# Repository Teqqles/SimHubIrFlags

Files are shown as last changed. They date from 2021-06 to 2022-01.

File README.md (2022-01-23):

# SimHubIrFlags

Custom serial device for pushing SimHub flag colours to inexpensive IR controlled RGB light strips.  Your mileage may vary on this project depending on which
IR light strips you are using.  Some for example have more latency than others, they do not allow for coloured light flashing, etc.

## Circuit 

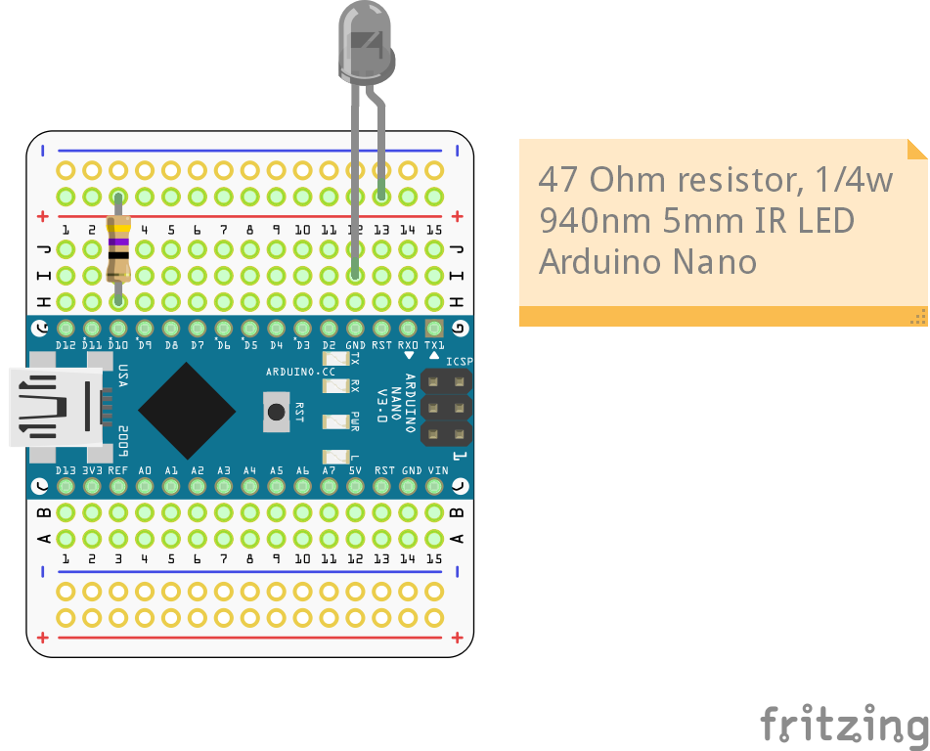
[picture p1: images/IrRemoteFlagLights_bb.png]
IR Circuit


## Parts

The parts I used in this project were:

- Cytron Maker Nano - https://thepihut.com/products/maker-nano <br>
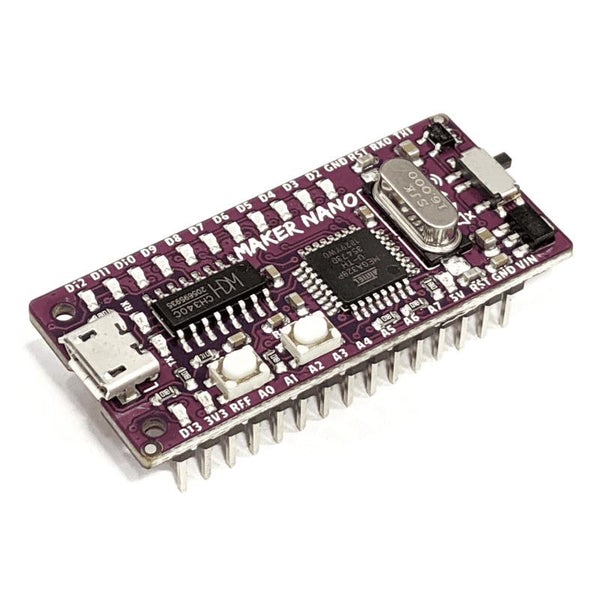
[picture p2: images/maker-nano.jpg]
Maker Nano
  
- 47 Ohm 1/4w Resistor - https://www.amazon.co.uk/Watt-Carbon-Resistor-0-25W-Tolerance/dp/B08Y2S1S6Z <br>
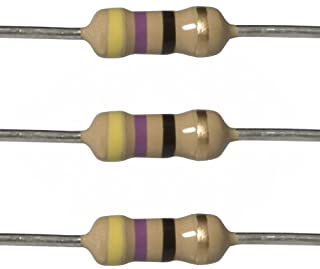
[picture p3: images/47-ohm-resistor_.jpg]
Resistor
  
- 940nm IR LED 5mm Package - https://thepihut.com/products/super-bright-5mm-ir-led <br>
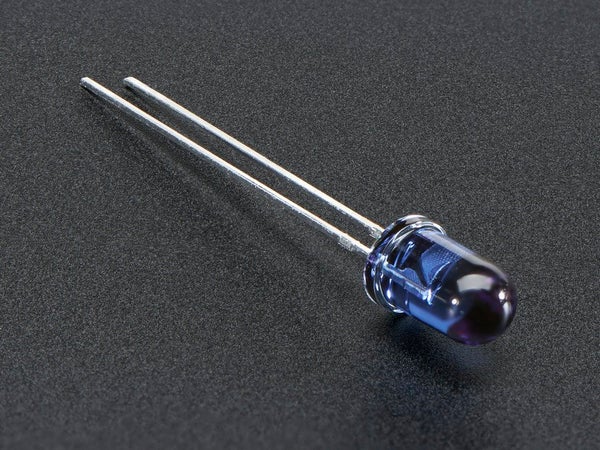
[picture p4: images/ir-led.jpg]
IR LED
  
- Clear fronted junction box (83mmx58mmx33mm) - https://www.amazon.co.uk/gp/product/B072FS3W7X
- Optionally a Perma-proto quarter sized board - https://thepihut.com/products/adafruit-perma-proto-quarter-sized-breadboard-pcb-single

## Compiling Instructions

Download a [release](https://github.com/Teqqles/SimHubIrFlags/releases) of the software into an appropriate folder. 

*Note: Arduino IDE likes the parent folder of a project to have the same name as the ino file so remove the version of the parent folder after extracting* 

Follow instructions on installing [Arduino IDE](https://www.arduino.cc/en/software) and download drivers for your Arduino compatible device.  In my case that 
is the Maker Nano and drivers can be found in <http://www.wch.cn/downloads/CH341SER_ZIP.html>, this project should work with other devices but you'll likely have
to change the IR_SEND_PIN (defaults to 10)

Install the [ArduinoJson](https://arduinojson.org/v6/doc/installation/) and [RemoteIR](https://www.ardu-badge.com/IRremote/zip) libraries

To compile this application for the IR light strip type you are using you can modify values in [IrForLedStrip.h](./IrForLedStrip.h)

Select the Arduino Nano as your device (Tools>Board>Arduino AVR Boards) and the appropriate com port for your device.

Hit `Ctrl+R` to make sure the sketch compiles and then `Ctrl+U` if you are happy to upload it to your device, then you can move onto SimHub.

## Configuring in SimHub

This project is built as a custom serial device which by default is hidden in SimHub.  In SimHub go to settings on the left hand nav, then  `Plugins`, from there
find and enable `Custom serial devices`.  This doesn't always immediately show up in the left and nave but if you close and reopen SimHub you should now see
`Custom serial devices` in the left hand nav, click it and expand the Custom Serial Device found there.  Set the port for your arduino project and the baudrate
to `11520`.  Enable RTS, Enable DTR, Log incoming data and Automatic reconnect should all be checked. 

Under the Update messages heading click edit and then click computed value.  Tick the `Use Javascript` box and enter in the command found on [this gist](https://gist.github.com/Teqqles/6145c6e3b0f63947ca54881a094439a2).

If the command is entered in correctly you should see under `Raw result`, something like:

```
{"flag":"X"}
```

Click OK and set the refresh rate.  For some of my light strips I have to set this to `Changes only`, others work best with 5-10hz.   Experiment a little with 
that and once you are happy with the result press the `Freeze/Unfreeze settings` button which will stop any further changes from being made to the messaging.

Ensure your serial device is enabled and now you should have working flags.  Congrats!

## Libraries used

Special thanks to the following, without which this project would have been a lot more complicated:

<https://github.com/bblanchon/ArduinoJson> - Arduino library for Json processing so we can have well formatted input.
<https://github.com/Arduino-IRremote/Arduino-IRremote> - Arduino library for sending and receiving IR instructions.

## Other sources

<http://woodsgood.ca/projects/2015/02/13/rgb-led-strip-controllers-ir-codes/> for the IR controller hex codes.

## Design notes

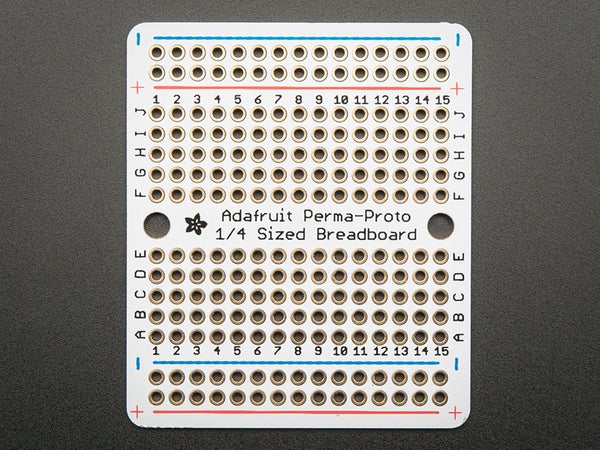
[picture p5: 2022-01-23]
images/perma-proto.jpg

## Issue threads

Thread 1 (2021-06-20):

Light strip powers off if already on

Teqqles, 2021-06-20:
Some lightstrips use the same IR code for switching on and off.  If a light strip is already on when SimHub connects in switches off.  Provide a flag to disable this feature so light strips remain on if they are already on.

Note:  This will disable the auto power on characteristics of the device and will need to be documented.

Closed 2021-06-20.

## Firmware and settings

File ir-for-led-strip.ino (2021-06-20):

/*
 *
 *  Copyright (C) 2021  David Long
 *  Email: teqqles@gmail.com
 *
 *  This file is part of SimHubIrFlags
 *
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
 */

#include "ir-for-led-strip.h"
#include "utils.h"
#include <IRremoteInt.h>
#include <ArduinoJson.h>

IrForLedStrip strip;
StaticJsonDocument<100> flagDoc;

void setup() {
  Serial.begin(115200);
  while (!Serial) continue; // wait for serial...
  strip.setup();
}

void loop() {
  if (Serial.available() > 0) // we have bytes for reading
  {
    String stringifiedJson = Serial.readStringUntil('\n');

    DeserializationError error = deserializeJson(flagDoc, stringifiedJson);
    if (error) {
      Serial.print("deserializeJson() failed: ");
      Serial.println(error.c_str());
      return;
    };
    const char *flagValue = flagDoc["flag"];
    if (strcmp(flagValue, "R") == 0) {
      strip.showFlag(remoteCodes.red);	
    } else if (strcmp(flagValue, "B") == 0) {
      strip.showFlag(remoteCodes.blue);
    } else if (strcmp(flagValue, "Y") == 0) {
      strip.showFlag(remoteCodes.yellow);
    } else if (strcmp(flagValue, "O") == 0) {
      strip.showFlag(remoteCodes.orange);	  
    } else if (strcmp(flagValue, "P") == 0) {
      strip.showFlag(remoteCodes.pink);   
    } else if (strcmp(flagValue, "G") == 0) {
      strip.showFlag(remoteCodes.green);
    } else if (strcmp(flagValue, "W") == 0) {
      strip.showFlag(remoteCodes.white);
    } else if (strcmp(flagValue, "D") == 0) { // not a flag but who doesn't like a demo?
      strip.demoPattern();       
    } else { // not a valid flag code so we switch back to neutral
      strip.showFlag(remoteCodes.neutral);
    }
    Serial.print("flag updated to :");
    Serial.println(flagValue);   
  }
}

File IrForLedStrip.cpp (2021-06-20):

/*
 *
 *  Copyright (C) 2021  David Long
 *  Email: teqqles@gmail.com
 *
 *  This file is part of SimHubIrFlags
 *
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
 */

#include "IrForLedStrip.h"
#include "Utils.h"
#include <Arduino.h>
#include <IRremote.h>

void IrForLedStrip::setup(){
  delay(4000); // To be able to connect Serial monitor after reset or power up and before first print out. Do not wait for an attached Serial Monitor!
  
  Serial.println(F("START " __FILE__ " from " __DATE__ "\r\nUsing library version " VERSION_IRREMOTE)); // Just to know which program is running

  IrSender.begin(IR_SEND_PIN, ENABLE_LED_FEEDBACK); // Specify send pin and enable feedback LED at default feedback LED pin

  Serial.print(F("Ready to send IR signals at pin "));
#if defined(ARDUINO_ARCH_STM32) || defined(ESP8266)
  Serial.println(IR_SEND_PIN_STRING);
#else
  Serial.println(IR_SEND_PIN);
#endif
#if not defined(DISABLE_POWER_ON)
  sendNecColors(remoteCodes.power);
#endif
  sendNecColors(remoteCodes.neutral); // Power on and put us in a neutral color
}

void IrForLedStrip::sendNecColors(IrFlag color) {
#if defined(VERBOSE_SERIAL_OUTPUT)
  debugPrintToSerial("IR Code: ", color.mainCode, HEX);
#endif 
  IrSender.sendNECMSB(color.mainCode, 32);
}

void IrForLedStrip::sendNecColors(IrFlag color, IrFlag flash) {
  sendNecColors(color);
  if (color.useFlash) {
    sendNecColors(flash);
  }
}

void IrForLedStrip::showFlag(IrFlag color) {
  sendNecColors(color, remoteCodes.flash);
}

void IrForLedStrip::demoPattern(){
#if not defined(DISABLE_POWER_ON)
  debugPrintToSerial("Power On");
  sendNecColors(remoteCodes.power);
  delay(2000);  
#else
  debugPrintToSerial("Power On disabled");	
#endif	
  debugPrintToSerial("Red Flag");
  sendNecColors(remoteCodes.red, remoteCodes.flash);
  delay(2000);
  debugPrintToSerial("Pink Flag");
  sendNecColors(remoteCodes.pink, remoteCodes.flash);
  delay(2000);  
  debugPrintToSerial("Yellow Flag");
  sendNecColors(remoteCodes.yellow, remoteCodes.flash);
  delay(2000); 
  debugPrintToSerial("Orange Flag");
  sendNecColors(remoteCodes.orange, remoteCodes.flash);
  delay(2000);    
  debugPrintToSerial("White Flag - Slow Car/Final Lap");
  sendNecColors(remoteCodes.white, remoteCodes.flash);  
  delay(2000);  
  debugPrintToSerial("Green Flag");
  sendNecColors(remoteCodes.green, remoteCodes.flash);
  delay(2000);    
  debugPrintToSerial("Blue Flag");
  sendNecColors(remoteCodes.blue, remoteCodes.flash);  
  delay(2000);    
  debugPrintToSerial("Neutral State");
  sendNecColors(remoteCodes.neutral, remoteCodes.flash);  
  delay(2000);     
  debugPrintToSerial("End of cycle");
}

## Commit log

2021-06-20 Rename files to better fit with Arduino IDE
2021-06-20 Cleanup debug and add flag for power on
2021-06-21 44 Button structure fixes
    Fixes to a number of faults found in testing
2022-01-23 Add circuit diagram and parts to readme. Bundle circuit diagram source file.
    [IrRemoteFlagLights.fzz]

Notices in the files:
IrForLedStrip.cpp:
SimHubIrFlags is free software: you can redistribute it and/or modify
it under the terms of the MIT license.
